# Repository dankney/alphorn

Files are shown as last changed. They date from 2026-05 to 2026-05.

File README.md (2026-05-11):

# 3D-Printable F Alphorn

A fully parametric, 3D-printable F alphorn designed for the Bambu Lab X1C with PLA wood filament. The instrument is a true F alphorn matching Jason Talbot's reference dimensions, splittable into 19 sections that all fit within a 256mm cubed build volume and join via airtight bayonet couplings.

The design is acoustically correct: the second harmonic plays at F2 (87 Hz) — the practical low note of an F alphorn — with the natural harmonic series within ±13 cents of equal temperament.

## Specifications

| | |
|---|---|
| **Pitch** | F (2nd harmonic ≈ 87 Hz) |
| **Total length** | 3880mm (388cm) |
| **Bore profile** | 14mm at mouthpiece → 92mm at bell start → 204mm at bell mouth |
| **Sections** | 19 (15 straight trunk + 3 curve + 1 bell mouth) |
| **Section length** | 204.2mm (max print height 247.7mm) |
| **Curve** | 45° upward bend (3 × 15° at the last three joints) |
| **Joint type** | Rectangular 3-lug bayonet twist-lock; sealed by friction + optional PTFE tape |
| **Wall thickness** | 9mm (trunk) → 10mm (bell), linearly interpolated |

## What's in this repository

| File | Purpose |
|---|---|
| `alphorn.scad` | Full parametric horn with assembly preview |
| `alphorn_print_layout.scad` | Self-contained file with all parts arranged flat for STL export |
| `alphorn_joint_test.scad` | Two-piece test print to validate the bayonet joint before printing all 19 sections |
| `alphorn_diagnostic.scad` | Single-section file with feature toggles for debugging mesh issues |

## Hardware required

- **Printer:** Bambu Lab X1C (or any FDM with ≥256mm build height)
- **Filament:** PLA wood (or any rigid PLA / PETG)
- **PTFE plumbers' tape** (optional, only if a joint develops a leak after assembly)
- **A mouthpiece** — not included in the print. Use either:
  - A commercial alphorn mouthpiece (Stocker, Eggerstorfer, etc.) with shank tip OD ≈ 12mm
  - The Talbot 20mm 3D-printed mouthpiece STL from [argobuilder.com](https://www.argobuilder.com/3d-printed-alphorn.html) — note: scale that STL to **10%** in the slicer

### Per-joint bolt reinforcement

The horn is too long to support itself as PLA alone — under playing-posture
loads (hands at the mouthpiece end), the first joint sees ~234,000 N·mm of
bending moment. Three M4 cap screws per joint, **oriented parallel to the
pipe axis with the threaded anchor in the female section's body wall**,
carry this load in tension alongside the bayonet lugs.

Each screw passes vertically (parallel to the pipe) from above through a
short radial tab on the upper section's body, drops through a clearance
hole in a longitudinal boss on the lower section's collar exterior, and
threads into a heat-set insert at the bottom of that boss. **Critical
geometry: 5 mm of the insert is anchored in the female section's *body*
proper (below the joint plane); only 1.4 mm sits in the collar.** This
puts the screw's lower anchor on the body side of the collar-body junction
— so even if that junction (the original failure zone) cracks, the screw
still ties the two sections together. After the +30° bayonet lock, the
three tabs land directly above the three collar bosses at 75°/195°/315°
in the lower section's frame.

Per joint:
- 3 × M4 × 30mm grade-10.9 socket-head cap screws
- 3 × M4 heat-set brass inserts (5.3 OD × 6.4 long — McMaster-Carr 92395A115 or equivalent)

Totals for the F horn (18 joints): 54 bolts, 54 inserts.
Totals for the Bb horn (13 joints): 39 bolts, 39 inserts.

Heat-press inserts into the **collar boss** pockets *before* final assembly
(soldering iron with M4 tip at ~200 °C). The 4.5 mm / 5.3 mm step in the
boss hole acts as a depth stop — the insert seats with its top at 1.4 mm
above the joint plane, leaving 18.6 mm of clearance hole above for the
screw shank. On assembly: insert the male section, twist 30° CCW to lock
the bayonet, then drive an M4 × 30 mm screw down through each tab into
the aligned insert below (~2 N·m).

## How to print

### 1. Test the joint first

Before committing to printing all 19 sections, print `alphorn_joint_test.scad` to validate the bayonet joint mechanics with your printer/filament combination. The test produces two short stubs (~50mm tall each) that share one joint at section 8/9 dimensions.

Verify after printing:

1. Lugs slide cleanly through axial slots
2. Quarter-turn locks the joint with a tactile stop
3. Joint is snug, not loose
4. Joint stays together when held vertically; halves don't pull apart under their own weight

If the lugs are too tight or too loose, adjust `BAYONET_CL` in the constants block.

### 2. Print orientation

All sections print **vertically**, small end (mouthpiece-side) **down**. This gives the cleanest bore surface, best layer adhesion along the air column, and requires no supports for sections 1-15. Sections 16-18 have an angled female face at the top — the body's flare is positioned to meet the collar's bottom rim cleanly on the low side of each tilted joint, so layer-by-layer overhangs along the body-to-collar transition stay below 25° from vertical (well within FDM bridging limits). The chamfer at the collar's open rim is the only feature on these sections that benefits from supports, and only at the rim itself; the slicer's automatic-support setting handles it.

### 3. Suggested batching plan (X1C plates)

| Plate | Contents | Approx width |
|---|---|---|
| 1 | Sections 1 + 2 | 110mm |
| 2 | Sections 3 + 4 | 120mm |
| 3 | Sections 5 + 6 | 135mm |
| 4 | Sections 7 + 8 | 155mm |
| 5 | Sections 9 + 10 | 180mm |
| 6 | Sections 11 + 12 | 205mm |
| 7 | Sections 13 + 14 | 235mm |
| 8 | Section 15 only | 134mm |
| 9 | Section 16 only | 155mm |
| 10 | Section 17 only | 175mm |
| 11 | Section 18 only | 205mm |
| 12 | Section 19 only | 227mm |

### 4. Recommended print settings

| | |
|---|---|
| Layer height | 0.2mm |
| Wall loops | 4 minimum |
| Infill (sections 1-15) | 20% |
| Infill (sections 16-19, bell) | 15% |
| Supports | None for 1-15; auto-supports at collar rim for 16-18 |
| Bed adhesion | Brim recommended for tall sections |

### 5. Workflow

1. Open `alphorn.scad` in OpenSCAD
2. Set `RENDER_SECTION = true` and `SECTION_NUMBER = N` for the section you want
3. Render with F6 (this can take a few minutes for the larger sections)
4. Export STL
5. Slice in Bambu Studio / Orca with the settings above
6. Repeat for sections 1-19

Or open `alphorn_print_layout.scad` to see all 19 sections laid out at once for visualization.

## Assembly

Each joint between adjacent sections N and N+1 works as follows:

1. **Section N+1's male end** has 3 rectangular lugs at 120° spacing protruding radially from the body wall just behind the open end
2. **Section N's female end** has a collar with three L-shaped slots cut into the inner socket — an axial entry channel and a tangential locking groove
3. **To assemble:** align the lugs on N+1 with the entry slots in N's collar, push N+1 in until the lugs bottom out, then twist about 30° to lock the lugs into the tangential lock channels. The PLA-on-PLA fit at the bayonet seals the joint by friction. If a particular joint develops a leak under playing pressure, wrap a single layer of PTFE plumbers' tape around the male shank before assembly.

Section numbers are recessed into the outer body wall at the small (male) end of each section, between the lugs — visible from outside before assembly, hidden behind the previous section's collar once joined.

For curve sections (16-18), the female collar is tilted 15° from perpendicular. The body's outer flare is shaped so the body wall reaches `collar_or` at the lowest point of the tilted joint plane (z = `len - collar_or × tan(15°)`), which makes the body's outer corner meet the collar's bottom rim within ~0.03mm on the low side of the bend. The result is a smooth body-to-collar transition all the way around the joint without an exposed ledge or unsupported overhang.

## Mouthpiece

The horn body bore at section 1's small end is 14mm ID. Standard alphorn mouthpieces have a shank tip OD of about 12mm and seat by taper friction at roughly 9mm depth into the bore. No glue, no threaded receiver — the mouthpiece simply press-fits and stays in place during play.

Sources:

- **Commercial:** Any alphorn mouthpiece (Stocker, Eggerstorfer, Tornister, etc.)
- **3D printed:** Talbot's 20mm cup mouthpiece STL on [argobuilder.com](https://www.argobuilder.com/3d-printed-alphorn.html). Important: that STL was exported at 10× scale, so import it and **scale to 10%** in your slicer. Print at 100% infill in PETG.

## Acoustic design

The bore follows a three-region profile from Talbot's reference drawings, expressed as the bore inner diameter at any axial position z:

- **Receiver (z=0 to 42mm):** linear taper from 16.7mm at the mouthpiece end down to 12.0mm at the receiver/trunk junction
- **Trunk (z=42 to 3140mm):** power law `bore_id(z) = 2 × (0.00026179 × (z − 41)^1.4849 + 5.9997)`
- **Bell (z=3140 to 3880mm):** quadratic `bore_id(z) = 0.00015273 × s² + 0.03833307 × s + 92.0` where `s = z − 3140`, C¹-continuous with the trunk slope at the junction

Each section's bore is subtracted as 8 stepped frustums following this profile, with maximum approximation error of 0.028mm. The bore is preserved at its acoustic profile right up to each joint plane — no internal flaring, no abrupt steps. The joint's mechanical clearance happens entirely above z=len in the female socket region, which is filled by the next section's male shank when assembled.

At 25°C effective playing temperature with end correction of 0.061m at the bell:

| Harmonic | Frequency | Pitch | Cents from equal temperament |
|---|---|---|---|
| 1 | 43.9 Hz | F1 (pedal) | +11 |
| **2** | **87.9 Hz** | **F2 (low note)** | **+11** |
| 3 | 131.8 Hz | C3 | +13 |
| 4 | 175.7 Hz | F3 | +11 |
| 5 | 219.7 Hz | A3 | −3 |
| 6 | 263.6 Hz | C4 | +13 |
| 8 | 351.5 Hz | F4 | +11 |

The uniform +11 cent offset reflects the assumed playing temperature; the player adjusts pitch by lipping and by Talbot's "trim to tune" technique on section 1. The 5th harmonic's natural −3 cents from equal-tempered A3 is characteristic of the harmonic series and matches the historical alphorn sound.

## Customizing the design

`alphorn.scad` is fully parametric. Key constants near the top:

| Constant | Default | Effect |
|---|---|---|
| `TOTAL_LENGTH` | 3880 | Overall horn length in mm |
| `NUM_SECTIONS` | 19 | Number of sections (don't reduce — 18 sections exceed X1C build height) |
| `CURVE_TOTAL_DEG` | 45 | Total bend angle in the bell region |
| `CURVE_JOINTS` | 3 | Number of joints sharing the bend |
| `BAYONET_CL` | 0.25 | Print clearance on lugs (increase if too tight) |
| `WALL_TRUNK` | 9.0 | Wall thickness at the mouthpiece end |
| `WALL_BELL` | 10.0 | Wall thickness at the bell mouth |

Changing these will automatically update the section profile table, batching plan, and acoustic length. Re-print the joint test if you change `BAYONET_CL`.

## Credits and references

This design is built on the work of Jason Talbot at [Argo Builder](https://www.argobuilder.com/), whose detailed measured drawings of a traditional Swiss alphorn made parametric reproduction possible:

- [Making an alphorn (wooden) — full dimensional drawings](https://www.argobuilder.com/making-an-alphorn.html)
- [3D printed alphorn — build log and STL files](https://www.argobuilder.com/3d-printed-alphorn.html)

Additional references:

- Flyby.ch [alphorn manufacture notes](http://www.flyby.ch/alphorn/herst_e.htm)

## License

Specify your preferred license here — common choices:

- **CC-BY-SA 4.0** — share-alike, requires attribution
- **MIT** — permissive, requires attribution
- **CC0** — public domain dedication

## Contributing

Pull requests welcome. If you build one of these and want to share photos or audio, please open an issue!

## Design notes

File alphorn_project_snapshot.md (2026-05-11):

# 3D Printable F Alphorn — Project Snapshot
**Date:** April 28, 2026
**Status:** OpenSCAD v7 — 19 sections, all parts fit X1C 256mm build height, print layout file complete

---

## Project Goal
Design a fully functional, playable F alphorn that can be 3D printed on a Bambu Lab X1C using PLA wood filament (via AMS), and assembled as simply as possible.

---

## Hardware & Materials
- **Printer:** Bambu Lab X1C
- **Build volume:** 256 × 256 × 256mm
- **Filament:** PLA wood filament via AMS
- **Slicer:** Bambu Studio

---

## Fundamental Geometry
The alphorn is a **single continuous hollow tapered tube** from mouthpiece to bell mouth. There is no separate bell attachment. The bell is simply where the taper flares more rapidly in the final 740mm. Each printed section is a plain hollow frustum with a rectangular bayonet joint integrated as part of the same connected mesh.

The instrument has a gentle **45° upward curve** in the bell region, distributed across the last three section joints (15°/joint × 3 joints).

---

## Files
| File | Purpose |
|---|---|
| `alphorn.scad` | Full parametric horn — 19 sections + mouthpiece + foot + assembly preview |
| `alphorn_print_layout.scad` | Self-contained file showing all parts arranged flat for printing reference |
| `alphorn_joint_test.scad` | Self-contained two-piece test print to validate the bayonet joint |

---

## Design Decisions Made
- **Tuning:** Standard F (388cm total)
- **Style:** Traditional sweeping curve (45° bend in bell region)
- **Joints:** Rectangular bayonet twist-lock with O-ring groove
- **Sections:** 19 identical-construction sections covering the full 3880mm bore
- **Bell:** NOT a separate piece — sections 17–19 are the bell region
- **Mouthpiece:** 20mm cup diameter (Talbot design), printed separately at 100% infill, shank tip seats directly in the section 1 bore by taper friction
- **Curve:** Angled female faces on sections 16, 17, 18 (15° each = 45° total)
- **Support foot:** Designed but excluded from assembly preview

---

## Section Count Rationale
The instrument was originally 18 sections × 215.6mm. Section 17 measured **258.7mm** in print orientation due to the angled female collar lifting one side ~24mm above the body — exceeding the X1C's 256mm build height. Increasing to 19 sections × 204.2mm brings worst-case section height to 247.7mm, comfortably within the build envelope while preserving the same total horn length (3880mm) and acoustic profile.

---

## Authoritative Dimension Source
Jason Talbot's alphorn drawings:
**https://www.argobuilder.com/making-an-alphorn.html**

His 3D printed alphorn build log:
**https://www.argobuilder.com/3d-printed-alphorn.html**

---

## Confirmed Dimensions

### Overall
| Parameter | Value |
|---|---|
| F horn trunk length | 314cm |
| Bell region length | 74cm |
| **Total horn length** | **388cm (3880mm)** |
| Wall thickness (trunk) | 7mm |
| Wall thickness (bell) | 8mm |

### Bore Reference Points
| Station | Inner Diameter | Outer Diameter |
|---|---|---|
| z=0mm (mouthpiece) | 14.0mm | 28.0mm |
| z=2200mm | 60.0mm | 74.0mm |
| z=3140mm (bell start) | 92.0mm | 106.0mm |
| z=3880mm (bell mouth) | 204.0mm | 220.0mm |

### Mouthpiece (Talbot 20mm)
| Parameter | Value |
|---|---|
| Total length | 105.17mm |
| Cup ID | 20.0mm |
| Cup OD | 31.84mm |
| Backbore D | 4.76mm |
| Shank length | 78.94mm |
| Shank tip OD / ID | 12.03 / 8.97mm |

The narrow shank tip inserts into the horn bore at z=0 and seats by taper friction at ~9mm depth.

---

## Bore Profile

### Trunk (z=0 to 3140mm) — Power Law
```
r(z) = 0.000250 × (z+1)^1.4849 + 6.9997
```

### Bell (z=3140 to 3880mm) — Quadratic
```
s = z - 3140
ID(s) = 0.00015474×s² + 0.036846×s + 92.0
```
C1-continuous with trunk slope at s=0. Reaches 204mm at s=740.

### Wall Thickness
Linear interpolation: 7.0mm at z=0 → 8.0mm at z=3880.

### Bore Subtraction
8-step subdivided frustum subtraction follows the curved profile. Max error 0.028mm. Bore is uninterrupted from z=0 to z=len within each section — **no internal flare** at joints. The bore preserves its acoustic profile right up to each joint plane. For curve sections (16–18), an additional bore extension above z=len prevents any solid-material plug from the angled-cut overhang.

### Full Section Profile Table (19 sections × 204.2mm)
| n | z_start | z_end | ID_start | ID_end | OD_start | OD_end | Curve? | Print Height |
|---|---|---|---|---|---|---|---|---|
| 1 | 0.0 | 204.2 | 14.00 | 15.39 | 28.00 | 29.54 | | 224.2mm |
| 2 | 204.2 | 408.4 | 15.39 | 17.86 | 29.54 | 32.13 | | 224.2mm |
| 3 | 408.4 | 612.6 | 17.86 | 21.04 | 32.13 | 35.45 | | 224.2mm |
| 4 | 612.6 | 816.8 | 21.04 | 24.79 | 35.45 | 39.36 | | 224.2mm |
| 5 | 816.8 | 1021.1 | 24.79 | 29.04 | 39.36 | 43.78 | | 224.2mm |
| 6 | 1021.1 | 1225.3 | 29.04 | 33.71 | 43.78 | 48.62 | | 224.2mm |
| 7 | 1225.3 | 1429.5 | 33.71 | 38.78 | 48.62 | 53.85 | | 224.2mm |
| 8 | 1429.5 | 1633.7 | 38.78 | 44.20 | 53.85 | 59.43 | | 224.2mm |
| 9 | 1633.7 | 1837.9 | 44.20 | 49.95 | 59.43 | 65.34 | | 224.2mm |
| 10 | 1837.9 | 2042.1 | 49.95 | 56.01 | 65.34 | 71.55 | | 224.2mm |
| 11 | 2042.1 | 2246.3 | 56.01 | 62.36 | 71.55 | 78.06 | | 224.2mm |
| 12 | 2246.3 | 2450.5 | 62.36 | 69.00 | 78.06 | 84.86 | | 224.2mm |
| 13 | 2450.5 | 2654.7 | 69.00 | 75.91 | 84.86 | 91.93 | | 224.2mm |
| 14 | 2654.7 | 2858.9 | 75.91 | 83.10 | 91.93 | 99.27 | | 224.2mm |
| 15 | 2858.9 | 3063.2 | 83.10 | 90.55 | 99.27 | 106.87 | | 224.2mm |
| 16 | 3063.2 | 3267.4 | 90.55 | 105.51 | 106.87 | 121.91 | **female 15°** ← bell | 240.3mm |
| 17 | 3267.4 | 3471.6 | 105.51 | 127.87 | 121.91 | 144.34 | **female 15°** | 243.1mm |
| 18 | 3471.6 | 3675.8 | 127.87 | 160.17 | 144.34 | 176.71 | **female 15°** | 247.7mm |
| 19 | 3675.8 | 3880.0 | 160.17 | 204.00 | 176.71 | 220.00 | (open mouth) | 204.2mm |

All sections fit within X1C 256 × 256 × 256mm build volume.

---

## Bayonet Joint Specification

Rectangular lugs and L-shaped slots in the female collar:

| Parameter | Value | Purpose |
|---|---|---|
| Lug count | 3 (at 120°) | Symmetric lock |
| Engagement depth | 15mm | Travel from open face to lock |
| Lug — radial (BAYONET_LUG_H) | 3.5mm | Protrusion outward |
| Lug — tangential (BAYONET_LUG_W) | 8mm | Width along circumference |
| Lug — axial (BAYONET_LUG_T) | 5mm | Thickness in slide direction |
| Lug embed (LUG_EMBED) | 1.0mm | Cube extends inward into body wall |
| Collar length | 20mm | At each end |
| Print clearance | 0.25mm | On lugs |
| O-ring groove | 2.5mm × 2.2mm | Fits 2mm cross-section O-ring |
| O-ring Z position (ORING_Z) | 10mm | Body-local z, just above lugs |
| Lock rotation | ~30° | Quarter-twist sweep |

---

## Unified Joint Methodology

**Every section uses one `difference()` block:**

**Outer hull (union):**
1. Body frustum (`od0` → `od_at_flare`)
2. External flare to collar OD (only if female end exists)
3. Female collar block on appropriate plane (only if female end exists)
4. Male lugs embedded 1mm into body wall (only if n > 1)

For curve sections, the body+flare are intersected with a tilted half-space below the collar plane.

**Subtractions:**
1. Bore profile (8-step curved frustum, z=0 to z=len)
2. Bore extension above z=len (curve sections only)
3. Inner socket (collar region, on tilted plane for curve sections)
4. L-channels (lug paths)
5. O-ring groove (cuts circumferential channel into outer body wall at ORING_Z=10)

### Per-Section Pieces
| Section | Female end | Male end | Notes |
|---|---|---|---|
| 1 | ✓ collar | — | Mouthpiece end (no male side) |
| 2–15 | ✓ collar | ✓ lugs + O-ring | Standard sections |
| **16** | ✓ collar (**15° angled**) | ✓ lugs + O-ring | First curve joint (bell start) |
| **17** | ✓ collar (**15° angled**) | ✓ lugs + O-ring | Curve joint |
| **18** | ✓ collar (**15° angled**) | ✓ lugs + O-ring | Curve joint |
| 19 | — (open bell mouth) | ✓ lugs + O-ring | Bell mouth section |

The test file (`alphorn_joint_test.scad`) uses identical joint methodology to a generic interior section.

---

## Curve Implementation
Sections 16, 17, 18 have their female end face cut at 15° instead of perpendicular. The female collar sits on the tilted face plane. Mating section's perpendicular male collar rotates that section's body axis by 15°.

- 45° total bend in bell region
- No length added — curves at existing joints
- OD unchanged at faces; wall thickness preserved
- Bore stays open with 15° kink at each joint (acoustically negligible at wide bell end)

Assembly preview uses recursive forward kinematics (`place_section_chain`) — walks up the horn, applying 15° rotation at each curve joint.

---

## OpenSCAD Module Inventory (`alphorn.scad`)
| Module / Function | Purpose |
|---|---|
| `bore_id(z)` | Inner diameter at any z (power law trunk + quadratic bell) |
| `wall_at(z)` | Wall thickness, linear 7→8mm |
| `bore_od(z)` | Outer diameter at z |
| `is_curve_section(n)` | True for sections 16, 17, 18 |
| `cumulative_curve(n)` | Total bend angle accumulated through section n |
| `taper_tube()` | Standalone hollow frustum |
| `horn_section(n)` | Single difference() that produces a complete connected section |
| `l_channels_only(od)` | L-shaped lug paths |
| `male_lugs(od)` | Three rectangular lugs embedded 1mm into body wall |
| `oring_groove(od, id)` | Circumferential channel cut into outer wall at ORING_Z=10 |
| `mouthpiece()` | 20mm cup mouthpiece, shank tip at z=0 |
| `support_foot()` | Ground peg with saddle clamp |
| `place_section_chain(n)` | Recursive forward kinematics for assembly preview |
| `full_assembly()` | Complete preview render |

### Render Control
```openscad
RENDER_ASSEMBLY   = true;   // full preview
RENDER_MOUTHPIECE = false;
RENDER_SECTION    = false;  // set SECTION_NUMBER = 1–19
RENDER_FOOT       = false;
```

---

## Print Layout File (`alphorn_print_layout.scad`)
Self-contained, no external dependencies. Renders all 19 sections + mouthpiece + foot arranged flat on the XY plane in optimal print orientation. Useful for visualizing the parts list.

### Batching Plan (X1C plates)
| Plate | Contents | Width |
|---|---|---|
| 1 | Sections 1 + 2 | ~110mm |
| 2 | Sections 3 + 4 | ~120mm |
| 3 | Sections 5 + 6 | ~135mm |
| 4 | Sections 7 + 8 | ~155mm |
| 5 | Sections 9 + 10 | ~180mm |
| 6 | Sections 11 + 12 | ~205mm |
| 7 | Sections 13 + 14 | ~235mm |
| 8 | Section 15 only | |
| 9 | Section 16 only | |
| 10 | Section 17 only | |
| 11 | Section 18 only | |
| 12 | Section 19 only | |
| 13 | Mouthpiece + foot | |

---

## Parts List
| Part | Qty | Notes |
|---|---|---|
| Horn sections 1–15 | 15 | Standard sections, perpendicular female face |
| Horn sections 16–18 | 3 | Angled (15°) female face for curve |
| Horn section 19 | 1 | Bell mouth, no female collar |
| Mouthpiece (20mm) | 1 | 100% infill |
| Support foot | 1 | Optional |
| O-rings (2mm cross-section) | 18 | One per joint |

---

## Open Issues / Next Steps

### Priority — next to do:
1. **Print the test file** (`alphorn_joint_test.scad`) — validate joint mechanics with PLA wood on X1C.
2. **Tune clearance if needed** — adjust `BAYONET_CL` based on test print fit.
3. **Visual verification of curve** — render the assembly preview and confirm the curve matches the photos.
4. **Bell mouth ring** — decorative/structural ring at section 19 exit.
5. **Tuning allowance** — Section 1 could be printed +160mm oversize for trim-to-tune.

### Nice-to-haves:
- AMS color accent rings at bayonet collars
- Edelweiss / Swiss cross relief on bell exterior
- Assembly jig for angled curve joints

---

## Print Settings (recommended)
| Setting | Value |
|---|---|
| Layer height | 0.2mm |
| Wall loops | 4 minimum |
| Infill — sections 1–15 | 20% |
| Infill — sections 16–19 (bell) | 15% |
| Infill — mouthpiece | 100% |
| Supports | None for sections 1–15, possibly partial for 16–18 angled overhang |
| Print orientation | Vertical, small end up |

---

## Known Issues Resolved
| Issue | Resolution |
|---|---|
| Wrong bore dimensions (11mm mouthpiece end) | Corrected to 14mm |
| Piecewise linear bore kink at 220cm | Smooth power law + quadratic |
| Bell modelled as separate piece | Removed — bell is sections 17–19 of same continuous tube |
| Internal geometry inside tube | Removed — sections are plain hollow frustums |
| Linear bore subtraction left 1.8mm ring inside bell | Fixed with 8-step subdivided bore subtraction |
| Support foot appearing inside bell in assembly | Removed from assembly preview |
| Mouthpiece receiver (wider pipe at mouthpiece end) | Removed — shank seats directly in bore |
| Stale no-op difference block in section 1 | Removed |
| Straight stick instead of curved alphorn | Added 45° bell curve via angled female faces on curve sections |
| Round slots / round lugs (geometry mismatch) | Rectangular lugs + L-shaped (rotate_extrude) slots |
| Cartesian cube slots left 0.293mm material slivers at edges | Slots and lock channels use rotate_extrude |
| Female collar floating disconnected from body | Body and collar unioned into single outer hull |
| Internal flare changed bore acoustics | External flare only — bore stays on profile to joint plane |
| Lugs only tangent-line-attached to curved body wall | Lugs embedded 1mm radially into body wall, unioned into outer hull |
| Curve sections had bore plug from angled-cut overhang | Bore extension cylinder added above z=len for curve sections |
| Lugs and O-ring groove placed below z=0 (outside body) | Removed bogus translate; ORING_Z=10 placed inside body |
| Curve section body construction inconsistent with straight | Unified outer hull construction; tilted half-space intersection only |
| **Section 17 was 258.7mm tall — exceeded 256mm build height** | **Increased section count from 18 to 19; max height now 247.7mm** |

---

## Reference Links
- Talbot wooden alphorn drawings: https://www.argobuilder.com/making-an-alphorn.html
- Talbot 3D printed alphorn + Fusion 360 files: https://www.argobuilder.com/3d-printed-alphorn.html
- Flyby.ch manufacture notes: http://www.flyby.ch/alphorn/herst_e.htm

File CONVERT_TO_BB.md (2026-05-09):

# Converting the F Alphorn to Bb

This document describes the parameter changes needed to generate a Bb alphorn from this design, keeping the leadpipe and mouthpiece receiver unchanged so the same mouthpiece works on either instrument.

> **If you just want to print the Bb horn**, use the pre-built `Bb_alphorn.scad` and `Bb_alphorn_print_layout.scad` files in this repository — the parameter changes below have already been applied. The rest of this document explains *why* those files have the values they do, and how to convert to other pitches.

## Overview

The Bb alphorn is approximately 25% shorter than the F alphorn because Bb2 (116.54 Hz) is a perfect fourth above F2 (87.31 Hz). For an open conical/expanding pipe, the playing pitch is inversely proportional to the acoustic length, so a higher pitch requires a shorter horn.

The leadpipe and mouthpiece receiver (z=0 to z=42mm, bore narrows from 16.7mm to 12mm) stay identical. Only the trunk and bell are rescaled.

## Length scaling

| | F horn | Bb horn |
|---|---|---|
| Target 2nd harmonic | F2 = 87.31 Hz | Bb2 = 116.54 Hz |
| Length ratio (Bb/F) | — | 0.754 |
| Total physical length | 3880mm (388cm) | 2935mm (294cm) |
| Receiver (unchanged) | 0-42mm, 16.7→12 | 0-42mm, 16.7→12 |
| Trunk | 42-3140mm, 12→92 | 42-2378mm, 12→69.4 |
| Bell | 3140-3880mm, 92→204 | 2378-2935mm, 69.4→154 |

The acoustic length ratio scales the trunk and bell uniformly. The receiver doesn't scale because its purpose is mouthpiece fitment, not pitch — its acoustic contribution is small relative to the trunk.

## Parameter changes in `alphorn.scad`

Replace the existing constants with these values:

```scad
TOTAL_LENGTH      = 2935;       // mm (was 3880)
TRUNK_LENGTH      = 2378;       // mm (was 3140) — where bell starts
NUM_SECTIONS      = 14;         // (was 19) — fewer sections needed,
                                //   chosen so the worst curve section
                                //   stays inside the X1C 256mm build
                                //   height (NUM_SECTIONS=13 would put
                                //   sections 10-12 above 256mm)

// Receiver — UNCHANGED
RECEIVER_LEN      = 42;         // mm
RECEIVER_TIP_ID   = 16.7;       // mm
RECEIVER_END_ID   = 12.0;       // mm

// Trunk power-law constants — refit so bore=12mm at z=42 and 69.36mm at z=2378
BORE_A            = 0.00028540; // (was 0.00026179)
BORE_N            = 1.4849;     // (unchanged)
BORE_C            = 5.9997;     // (unchanged — equals 6 by construction)

// Bell quadratic constants — refit, C¹-continuous with new trunk slope at z=2378
BELL_A            = 0.00020673; // (was 0.00015273)
BELL_B            = 0.03644530; // (was 0.03833307)
BELL_C            = 69.3586;    // (was 92.0) — bore at start of bell
```

Other constants (wall thickness, bayonet dimensions, clearances) stay the same. The wall thickness function `wall_at(z) = WALL_TRUNK + (WALL_BELL - WALL_TRUNK) * (z / TOTAL_LENGTH)` interpolates by fraction of total length, so it automatically adjusts for the shorter horn.

## Sections

The Bb horn uses 14 sections of 209.6mm each. The print height of the worst-case section (section 13, the last curve section) reaches 246.7mm — comfortably inside the X1C's 256mm build envelope and roughly the same margin as the F horn's worst case (247.7mm).

A naive `2935 / 13 ≈ 226mm` per-section calculation would seem to fit the X1C too, but it actually doesn't: the curve sections (with their tilted collars) gain `collar_or × sin(15°) + collar_h × cos(15°)` ≈ 37mm of extra height on top of the section length, and at 13 sections, sections 10-12 land between 257 and 262mm. NUM_SECTIONS = 14 is the smallest count that fits all curve sections under 256mm.

| | F horn | Bb horn |
|---|---|---|
| Sections | 19 | 14 |
| Section length | 204.2mm | 209.6mm |
| Worst-case section height | 247.7mm | 246.7mm |
| Curve placement | Last 3 joints (15° each) | Last 3 joints (15° each) |
| Total bend | 45° | 45° |

The curve position (last 3 joints) and per-joint angle (15°) stay the same since these define the visual character of the alphorn rather than the pitch.

## Acoustic verification

| | F horn | Bb horn |
|---|---|---|
| Acoustic length (with bell end correction) | 3941mm | 2982mm |
| Predicted 2nd harmonic (at 25°C) | 87.87 Hz | 116.15 Hz |
| Target | F2 = 87.31 Hz | Bb2 = 116.54 Hz |
| Cents from equal-tempered | +11 | −6 |

Both horns are within typical "lip into tune" range for a brass instrument. The player adjusts pitch by lipping and by Talbot's "trim to tune" technique on the mouthpiece end of section 1.

## Mouthpiece compatibility

Because the receiver geometry is unchanged, **the same mouthpiece works on both horns**. A standard alphorn mouthpiece with a 12mm-OD shank tip seats by taper friction at ~14mm depth into the receiver, regardless of which horn it's on. The Talbot 20mm 3D-printed mouthpiece STL (scaled to 10% in the slicer) works on both.

## Joint hardware

Bayonet dimensions (`BAYONET_LUG_H`, `BAYONET_LUG_W`, `BAYONET_LUG_T`, `BAYONET_COLLAR`, `BAYONET_CL`) stay the same. The joint is sized for mechanical strength and printability, not pitch. PTFE plumbers' tape (if needed at all) works the same way on either horn.

The curve sections' body-to-collar flare geometry — where the body's outer flare reaches `collar_or` at z = `len − collar_or × tan(angle)` so the body's outer corner coincides with the collar's bottom rim on the low side of each tilted joint — is computed per-section from `collar_or` (which depends on the section's own bore) and `angle` (which is the per-joint curve angle, unchanged at 15°). It auto-adjusts for the smaller `collar_or` values of the Bb horn's curve sections without any code changes. Spot-check after conversion that `body_h_c = flare_top_z_c − flare_h` remains positive for the curve sections; for typical alphorn proportions across pitches from C through Eb, this is comfortably the case.

## Implementation steps

1. Edit `alphorn.scad` with the parameter changes above (or start from the prebuilt `Bb_alphorn.scad` if you have it)
2. Re-render the assembly preview to verify the curve and overall proportions look right
3. Run the acoustic verification (Phase 9 prompt 23 in `RECREATE_WITH_CLAUDE.md`) — predicted 2nd harmonic should be ~116 Hz
4. Regenerate `alphorn_print_layout.scad` from scratch — the layout was generated for 19 sections and the section count, length, and OD profile all change for Bb
5. Print a fresh joint test piece. The joint geometry is unchanged so the existing F-horn test print still validates the fit; the dimensions sample at mid-section (around the section 7/8 boundary in the 14-section design)
6. Print all 14 sections per the new batching plan

## Bore profile reference points (Bb horn)

For verification or comparison:

| z (mm) | Region | Bore ID (mm) |
|---|---|---|
| 0 | Receiver tip | 16.70 |
| 42 | Receiver / trunk junction | 12.00 |
| 500 | Trunk | 17.12 |
| 1000 | Trunk | 27.28 |
| 1500 | Trunk | 40.50 |
| 2000 | Trunk | 56.14 |
| 2378 | Trunk / bell junction | 69.36 |
| 2700 | Bell | 102.53 |
| 2935 | Bell mouth | 153.80 |

## Other pitches

The same approach works for any alphorn pitch. The length scaling factor is `f_F / f_target`, where `f_target` is the desired 2nd harmonic. Common alphorn pitches:

| Pitch | 2nd harmonic | Scale factor (vs F) | Approx. total length |
|---|---|---|---|
| Eb (concert pitch) | 77.78 Hz | 1.123 | 4357mm |
| E | 82.41 Hz | 1.060 | 4112mm |
| F | 87.31 Hz | 1.000 | 3880mm |
| F# | 92.50 Hz | 0.944 | 3661mm |
| G | 98.00 Hz | 0.891 | 3457mm |
| Ab | 103.83 Hz | 0.841 | 3262mm |
| A | 110.00 Hz | 0.794 | 3079mm |
| Bb | 116.54 Hz | 0.749 | 2935mm |
| B | 123.47 Hz | 0.707 | 2742mm |
| C | 130.81 Hz | 0.667 | 2589mm |

For each pitch, recompute `BORE_A`, `BORE_C`, `BELL_A`, and `BELL_B` to fit:
- Trunk: 12mm at z=42, scaled-92 at the new TRUNK_LENGTH
- Bell: scaled-92 at TRUNK_LENGTH, scaled-204 at TOTAL_LENGTH
- Bell slope at TRUNK_LENGTH must match the trunk slope (C¹ continuity)

The receiver and joint dimensions stay constant across all pitches — only TOTAL_LENGTH, TRUNK_LENGTH, NUM_SECTIONS, and the four bore/bell constants change.

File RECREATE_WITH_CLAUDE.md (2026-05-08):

# Recreating the F Alphorn Design with Claude Opus 4.7

This document captures the sequence of prompts that produced the parametric F alphorn OpenSCAD model in this repository. Each prompt is written as a standalone instruction Claude can act on; the sequence reflects the iterative discovery process that uncovered constraints and bugs along the way.

The original session took many hours and went through several major redesigns as constraints surfaced — bore profile, joint mechanics, mesh integrity, FDM printability, label visibility, and acoustic continuity all interacted in ways that weren't obvious up front. This guide bakes those lessons in so a recreation can be more efficient.

## How to use this document

Open a Claude conversation with **Opus 4.7** (the model needs strong spatial reasoning and patience for long iterative debugging). Feed the prompts in order, one at a time, waiting for Claude to produce code and confirm before proceeding. After major milestones, ask Claude to "take a snapshot" so you have rollback points if a later change breaks something.

You will need to provide Claude with reference material at the appropriate steps — primarily Jason Talbot's dimensional drawings from [argobuilder.com](https://www.argobuilder.com/making-an-alphorn.html). Download those drawings as images (sheets 1-8) and upload them when prompted.

If a step doesn't produce the expected result, don't push forward — debug in place. The single biggest lesson from the original session was that downstream geometry depends critically on the soundness of upstream geometry, and shortcuts compound. The second biggest lesson was that geometry that looks right in the OpenSCAD preview can still be broken in the STL export — always verify in the slicer.

## Prerequisites

Make sure these are mentioned to Claude up front (or set as part of an early prompt):

- Target printer: Bambu Lab X1C, 256mm cubed build volume
- Target filament: PLA wood (via AMS)
- Target slicer: Bambu Studio / Orca Slicer
- Output format: OpenSCAD `.scad` files
- The horn must be airtight, acoustically correct, splittable into print-bed-sized sections, and reassemblable without tools

## Phase 1: Establish the basic instrument

### Prompt 1 — Initial design brief

> I want to design a 3D-printable F alphorn for my Bambu Lab X1C printer using PLA wood filament. The instrument should be acoustically correct and playable. Please use Jason Talbot's dimensional drawings from argobuilder.com as the authoritative source. Plan an initial parametric OpenSCAD design that splits the horn into sections small enough to fit on the X1C bed (256mm cubed). Each section should have an integrated joint mechanism so the horn can be assembled and disassembled. The horn should be a single continuous tapered tube — the bell is just the final sections of the same bore where it flares more rapidly, not a separate piece.

### Prompt 2 — Provide reference dimensions

> I'm uploading the eight Talbot dimensional drawing sheets (IMG_5096-5104). Please extract the bore profile dimensions, wall thicknesses, and total length from these drawings and use them as the authoritative source for the model. The horn should be 388cm total (Talbot's F# spec of 373cm + 16cm tuning extension to make F).

(Upload the Talbot drawing scans here.)

### Prompt 3 — Bore profile with mouthpiece receiver

> The bore profile has three regions:
>
> 1. **Mouthpiece receiver (leadpipe tip)**, z=0 to z=42mm: linear taper NARROWING from 16.7mm at the very tip to 12.0mm at z=42. This is the only region where the bore narrows — it provides the cup-like constriction needed for a mouthpiece to seat by taper friction.
> 2. **Trunk**, z=42 to z=3140mm: power-law expansion from 12mm at z=42 to 92mm at z=3140. Use form `bore_id(z) = 2*(A*(z-42+1)^N + C)` with N≈1.4849 and fit A and C to those endpoints.
> 3. **Bell**, z=3140 to z=3880mm: quadratic, C¹-continuous with the trunk slope at z=3140, reaching 204mm at z=3880.
>
> Wall thickness should linearly interpolate from 7mm at z=0 to 8mm at z=3880.

### Prompt 4 — Snapshot

> Take a snapshot. Save the current files as a timestamped zip so we can roll back if needed.

## Phase 2: Add the curve

### Prompt 5 — Distributed curve

> The horn should have a 45° upward bend in the bell region, distributed across the last three section joints (15° per joint). Implement this by angling the female mating face of the affected sections at 15° instead of perpendicular. The mating section attaches perpendicular to that tilted face, so its body axis ends up rotated 15° relative to the previous section. Each individual printed section remains a straight piece — the curve emerges from how they connect. Add an assembly preview that uses recursive forward kinematics to walk up the horn applying the rotation at each curve joint.

## Phase 3: Bayonet joint design

### Prompt 6 — Initial joint geometry

> Design a bayonet twist-lock joint between sections. **Do NOT include an O-ring groove** — relying on O-rings means sourcing 18 different stretch sizes, and PLA-on-PLA friction at the bayonet is sufficient. PTFE plumbers' tape can be added at assembly if a leak appears. Each joint should have:
>
> - A male collar at the small end of each section (sections 2-19) with 3 rectangular lugs at 120° spacing, each 8mm tangentially × 5mm axially × 3.5mm radially
> - A female collar at the large end of each section (sections 1-18) with three L-shaped slots cut into the inner socket — an axial entry channel for the lug to insert, plus a tangential lock channel that engages when the male is rotated ~30°
> - Lugs embedded 1mm into the body wall (cube inner face goes from `od/2 - 1` to `od/2 + 3.5` so the lug overlaps the body's curved surface in 3D, not just on a tangent line)
> - Slots and lock channels swept using `rotate_extrude` of a square profile so all edges follow the cylinder's curvature

### Prompt 7 — Iterative joint debugging

These prompts may be needed depending on what surfaces. Apply only as relevant:

> The female collar is rendering as a separate piece adjacent to the body rather than being part of the same mesh. Restructure `horn_section` so the body, flare, and collar are all unioned into a single outer hull, then all subtractions (bore, inner socket, L-channels) happen in one `difference()`. This guarantees a single connected mesh.

> There is a visible air gap between the female collar and the segment body where the radii change. Add a 0.5mm overlap so the collar extends slightly into the body region (3D volume overlap, not just a 2D shared face).

> The whole horn should have an unobstructed air path from mouthpiece to bell. There are obstructions on curve sections — the angled female face cuts the body at 15°, leaving body material above z=len that the bore subtraction doesn't reach. Add a constant-radius bore extension above z=len for curve sections to prevent any solid-material plug.

### Prompt 8 — Snapshot

> Take a snapshot.

## Phase 4: Print layout and printability

### Prompt 9 — Self-contained print layout

> Without modifying the main model, create a separate self-contained OpenSCAD file that arranges all parts on the XY plane in optimal print orientation (small end down for sections). Don't reference the main model with `use` or `include` — copy all needed constants and modules so the file works on its own. Include a batching plan in the comments showing which sections fit together on a single 256mm bed plate.

### Prompt 10 — Build height check

> The largest sections might exceed the X1C's 256mm build height when printed vertically. Calculate the precise print height for each section, accounting for the angled collar lift on curve sections (where one side of the tilted collar rises by `collar_or × sin(15°)`). If any section exceeds 256mm, increase the section count and reduce per-section length until all fit, while keeping total horn length and the curve placement unchanged.

### Prompt 11 — FDM printability of angled rim

> The angled female face on curve sections has overhangs flatter than 45° from horizontal at the rim — too flat for FDM without supports. Add a 45° chamfer (5mm × 5mm) at the outer rim of every female collar that bevels the open face. Apply to all sections so straight sections also get a clean rim, but it's especially critical for the curve sections where the face is tilted.

### Prompt 12 — Smooth body-to-collar transition

> Add a gentle slope at the body-to-collar transition. The flare zone where the body OD widens up to the collar OD should be 25mm long, giving roughly a 17° slope from vertical — very gentle and visually seamless with no abrupt edge.

### Prompt 13 — Printable lug bottoms

> The bottom face of each male lug at z=2.5 has a 3.5mm radial overhang past the body wall — too wide for FDM bridging. Rebuild each lug as a `hull()` of two pieces: a top cube with the original full radial extent (engages with the lock channel), and a thin bottom slab that protrudes only 1mm past the body wall. The hull creates a 45° printable ramp on the outer-bottom corner of each lug. The top portion still has full extent so it engages firmly with the female lock channel — the chamfered bottom region just doesn't engage with the channel walls (which is fine, since locking happens at the lug's top face).

### Prompt 13b — Curve-section body-to-collar overhang (the "low side ledge")

> On curve sections (16-18), the standard body polygon flares from `od_at_flare/2` at z=`body_h` up to `collar_or` at z=`len`, then continues at constant `collar_or` to z=`len + max_overhang`. The whole polygon is then clipped at the tilted joint plane (`z = len + y·tan(angle)`). On the LOW side of the tilted plane, this clip cuts the body well before the flare reaches `collar_or`, leaving the body wall ending at a smaller radius than the collar's bottom rim — which sits 2-6mm outboard. The visible result is a sharp 85°+ overhang where the slicer has to bridge from body wall outline to collar wall outline within a single layer. Slicer's overhang detector flags it as severe, and the rim arches print with stringy/sagging layers.
>
> The fix is geometric, not additive: move the flare's top vertex from `(collar_or, len)` to `(collar_or, len - collar_or × tan(angle))`. That z is the exact height where the tilted clip plane on the low side would intersect the body cylinder at radius `collar_or`. With the new vertex, the body's outer corner on the low side coincides (within ~0.03mm) with the collar's bottom rim. Above that vertex, the polygon stays at constant `collar_or` up to `len + max_overhang`, so the tilted clip carves a clean joint plane that runs straight into the collar at every angle around the section.
>
> Compute the new flare bottom vertex consistently:
> ```scad
> flare_top_z_c = len - collar_or * tan(angle);
> body_h_c     = flare_top_z_c - flare_h;
> od_at_flare_c = od0 + (od1 - od0) * (body_h_c / len);
> ```
> Use these in the polygon for curve sections only — straight sections (`angle == 0`) are unchanged because `tan(0) = 0`, which collapses `flare_top_z_c` back to `len`. Worst-case layer-by-layer overhangs along the body-to-collar transition drop from 85°+ to under 25° from vertical, which is well within FDM bridging limits and stops the slicer from flagging the joint.
>
> Important things NOT to do, even though they look reasonable in isolation: do **not** add a tilted "flange" or downward extension of the collar to fill the ledge. A tilted addition has its bottom edge at a different world z at every angle, so the bottom edge dips low on the LOW side where the body is narrow — the flange's bottom edge then sticks 2-6mm outboard of the body wall there, recreating the same severe overhang one layer below where it started. Any solution that tries to bridge the ledge with material added OUTSIDE the body's existing rotate-extruded polygon will hit this trap. The fix has to be in the polygon itself.

## Phase 5: Mesh integrity (critical iteration)

The original session encountered persistent disconnected-mesh problems that took many iterations to fully resolve. The OpenSCAD preview will show one piece, but the STL export can have disconnected shells. **Always slice the STL in Orca and check** — don't trust the preview.

### Prompt 14 — Detect disconnected shells

> When I split this design into print objects in Orca Slicer, I see N thin rings appearing as separate objects. The geometry is supposed to be a single connected mesh per section. Audit the model for adjacent solids that share only a 2D face (or near-degenerate boundaries from nested boolean operations) — those produce separate mesh shells in STL export even though OpenSCAD's CSG considers them unioned.

### Prompt 15 — Restructure as single rotate_extrude

> Replace the stacked-cylinder construction (body + flare + collar as separate cylinders unioned together) with a single `rotate_extrude` of a closed 2D polygon that traces the entire outer profile from base through the flare and collar in one continuous path. This guarantees one solid with no internal shared faces. For curve sections that need a tilted collar, keep the rotate_extrude for the body+flare and add the tilted collar as a separate solid with a small overlap.

### Prompt 16 — Diagnostic file for ring isolation

> If rings are still appearing, create a diagnostic OpenSCAD file with a single section and feature toggle flags at the top (`FEATURE_FLARE`, `FEATURE_FEMALE_COLLAR`, `FEATURE_INNER_SOCKET`, `FEATURE_L_CHANNELS`, `FEATURE_SECTION_LABEL`, `FEATURE_COLLAR_CHAMFER`, `FEATURE_MALE_LUGS`, `FEATURE_BORE`). I'll toggle features on one at a time, export STL, and check Orca to identify which feature introduces the disconnect. Don't guess at the cause — the bisection takes 5-10 minutes and gives a definitive answer.

### Prompt 17 — Eliminate degenerate boundaries

> If a feature is identified as the disconnect source, look for nested `difference()` operations or subtraction shapes whose outer boundary lies essentially on the body's outer surface (within 0.1mm). These produce near-degenerate boundaries in CGAL that become disconnected shells. Rewrite any such shape using a single `rotate_extrude` of a polygon profile, and extend any subtraction shapes well beyond the body OD (5mm past) so there's no marginal overlap with the body's outer surface.

## Phase 6: Section labels — get this right the first time

The original session went through **four different label placement attempts** before settling on the working one. Skip the failures by going straight to the right answer.

### Prompt 18 — Section labels on body wall between lugs

> Each section should have its number recessed into the OUTER body wall at the small (male) end of each section, in the clear space between the lugs (lugs at 0°, 120°, 240°; place label at 60°). Position parameters:
>
> - z = 18mm above the section's bottom face (well above lug top at z=7.5)
> - Angular position: 60° (between two adjacent lugs)
> - TEXT_SIZE = 16mm character height
> - TEXT_DEPTH = 1.2mm recess depth
> - Bold sans-serif font (Liberation Sans:style=Bold)
>
> Implementation gotchas:
>
> 1. The text shape must extrude RADIALLY INWARD into the wall, not outward into empty space. Position the text origin at `r = od0/2 + TEXT_DEPTH` and use `rotate([0, -90, 0]) rotate([0, 0, -90])` so the local +Z extrusion direction points inward toward the body axis.
> 2. Add `mirror([1, 0, 0])` before the linear_extrude — without it, when viewed from outside the body, the digits read mirrored (e.g., "10" appears as "01").
> 3. Make the extrude height slightly more than TEXT_DEPTH (TEXT_DEPTH + 0.2) to ensure full cut-through.
>
> The label is recessed into the body wall just above the lug zone, always visible from outside before assembly, hidden inside the previous section's collar after assembly. This is on a simple cylindrical surface that's identical for every section regardless of curve angle, so it works uniformly across all sections.

**Anti-patterns to avoid** — these were tried and failed:

- Recessed text on the inner socket wall (not visible looking down into a 20mm-deep socket)
- Embossed text on the flat top face of the collar (would create a 0.8mm gap at every joint when assembled, blocking the seal)
- Recessed text on the collar's outer cylindrical surface (works for straight sections but the angled rim of curve sections cuts through it unpredictably)

The body wall between lugs is the only location that works for all sections.

## Phase 7: Bore continuity at joints

### Prompt 19 — No "print ramp" inside the body

> Do NOT add an internal ramp or chamfer that widens the bore at the top of each body section, even if it would help printability when printing collar-down. Such a ramp creates a 6-7mm thick annular pocket of dead air at every joint when assembled — section N's widened bore opens into the smaller-bore start of section N+1, leaving an empty annular cavity around the bore. This is acoustically destructive (18 such pockets in series).
>
> The bore at every joint must be continuous: section N's bore at z=len equals section N+1's bore at z=0 because both evaluate `bore_id` at the same absolute z. If printing collar-down has overhang issues, the fix is to print small-end-down instead (the original orientation), or use slicer-generated supports. Don't compromise the bore.

### Prompt 20 — Handle the receiver kink in bore subtraction

> Section 1's bore profile has a kink at z=42mm where the receiver taper (narrowing) meets the trunk expansion. The default 8-step frustum approximation linearly interpolates across this kink and will be off by ~0.7mm at z=42. Fix this for section 1 specifically: use a single cone subtraction for the receiver (z=0 to z=42), then start the standard 8-frustum subdivision at z=42 for the trunk portion. This places the kink exactly on a frustum boundary so it's rendered without approximation error.

### Prompt 21 — Snapshot

> Take a snapshot.

## Phase 8: Joint test print

### Prompt 22 — Bayonet joint test print

> Before committing to printing all 19 sections, create a self-contained two-piece test print file that validates the bayonet joint mechanics. Use the dimensions from the section 8/9 boundary (mid-trunk size — representative without being huge). Each test piece should be a short body stub (~50mm tall) with one half of the joint attached. Include verification steps in the file's header comments: lugs slide cleanly through slots, quarter-turn locks the joint, joint is snug but not too tight, joint stays together when held vertically. If the lugs are too tight or too loose, adjust `BAYONET_CL` (default 0.25mm).

## Phase 9: Verification

### Prompt 23 — Acoustic verification

> Verify acoustically that the design is correctly pitched in F. Check the harmonic series at typical playing temperature (warm humid breath inside the horn ≈ 25°C). The 2nd harmonic (the practical low note of an F alphorn) should be approximately F2 (87.31 Hz). Calculate the fundamental and at least the first 8 harmonics, comparing each to its equal-tempered target in cents. Account for end correction at the bell mouth (≈0.6 × bell_radius). Also verify the bore matches Talbot's reference points: 14mm at z=0 (was — now 16.7mm because of the receiver), 60mm at z=2200mm (allow ~2% deviation due to receiver), 92mm at z=3140mm (must match), 204mm at z=3880mm (must match).

### Prompt 24 — Mouthpiece compatibility check

> The horn should accept a standard alphorn mouthpiece with a 12mm-OD shank tip tapering to ~29mm at the cup shoulder over 79mm. Verify the mouthpiece seats by taper friction in the receiver. Calculate the depth at which shank OD equals receiver bore ID (linear taper from 16.7 to 12 over 42mm). Confirm it's a snug fit at a reasonable depth (~10-15mm into the receiver). The mouthpiece itself is supplied separately by the user — do not include it in the model. The Talbot 20mm 3D-printed mouthpiece STL from argobuilder.com works (note: that STL must be scaled to 10% in the slicer — Talbot exported it at 10× scale).

## Phase 10: Documentation

### Prompt 25 — README

> Create a comprehensive README.md for this GitHub repository. It should include:
>
> - Specifications table (pitch, dimensions, joint type)
> - File-by-file purpose
> - Hardware required (no O-rings — sealing is by friction + optional PTFE tape)
> - Build instructions starting with the joint test
> - Plate-by-plate batching plan
> - Recommended print settings (small-end-down orientation)
> - Assembly procedure
> - Mouthpiece sourcing notes (commercial or Talbot STL with 10% scaling)
> - Acoustic design summary with the harmonic series table and bore profile equations
> - Customization guide for the parametric constants
> - Credits to Jason Talbot's reference work
> - License placeholder

### Prompt 26 — Final snapshot

> Take a final snapshot.

## Anti-patterns and lessons learned

Things the original session tried that turned out to be wrong. Don't repeat these.

**O-ring grooves are not worth the trouble.** Sourcing 18 different stretch sizes (24mm to 168mm ID) is fiddly. The groove geometry creates printability issues (unsupported overhang above the groove). PLA-on-PLA friction at the bayonet is adequate; PTFE plumbers' tape solves any leak. The acoustic compliance of a brass-style instrument tolerates some leak at joints anyway.

**The OpenSCAD preview cannot be trusted for mesh integrity.** Geometry that looks like a single connected piece in the preview can export as multiple disconnected shells in the STL. Always import the STL into Orca Slicer and check for separate objects.

**Nested CSG operations create degenerate boundaries.** Subtraction shapes built as `difference()` of two cylinders (e.g., to make an annular ring) often have outer boundaries that lie nearly on the body's outer surface — within 0.1mm. CGAL handles these unreliably and produces disconnected mesh shells. Build subtraction shapes as single `rotate_extrude` polygons instead, with outer boundaries well past the body OD (5mm past).

**Adjacent cylinders sharing only a 2D face produce separate STL shells.** Stacking cylinders end-to-end (`translate([0,0,h]) cylinder(...)` immediately above another cylinder) creates a 2D shared face that triangulation can't reliably handle. The solution is to build the entire body+flare+collar profile as a single `rotate_extrude` polygon — one closed path, one revolution, one solid.

**Section labels are hard to place. The body wall between lugs is the only location that works.** The inner socket wall is not visible looking straight down into a 20mm-deep socket. The collar's top face would block joint sealing. The collar's outer cylindrical surface fails for angled curve sections. The body wall at z=18 between lugs is a simple cylindrical surface, identical for every section, always visible from outside the horn.

**Don't compromise the bore for printability.** Adding an inner ramp to make collar-down printing easier creates an annular pocket at every joint — 18 pockets in series destroys the air column. Either print small-end-down (no overhang issue) or use slicer-generated supports. Keep the bore profile pure.

**The receiver bore profile has a kink at z=42mm.** The default 8-step bore subdivision linearly interpolates across this kink and produces ~0.7mm error in the rendered bore at the kink. Section 1 needs special handling: separate the receiver subtraction from the trunk subdivision, with z=42 as the boundary.

**Lug bottoms have a 3.5mm overhang.** Unless the lugs are chamfered with a `hull()` of two cubes (small bottom slab + full top), the printer drools layers across this overhang and the lugs print rough. The chamfer reduces the overhang to 1mm without compromising the lock engagement at the lug top.

**The curve sections' body-to-collar transition is fixed in the polygon, not by adding a flange.** It's tempting to "patch" the body-to-collar ledge on the low side of curve sections by adding a separate flange or extending the collar downward. Every additive approach fails the same way: any tilted piece has its bottom edge at varying world z, dipping low on the LOW side where the body is narrow, so the bottom edge protrudes 2-6mm outboard of the body wall there and just relocates the severe overhang. The right fix is to move the body polygon's flare-top vertex to z = `len − collar_or × tan(angle)` so the body itself reaches `collar_or` at the lowest point of the tilted joint plane. The body's outer corner then coincides with the collar's bottom rim within 0.03mm and the overhang vanishes.

**Mirror text or it reads backwards.** Recessing text into a curved surface from outside, the natural orientation makes the text read mirrored when viewed from outside. Add a `mirror([1, 0, 0])` before linear_extrude to flip it. This was discovered after the first complete print attempt — the digits were perfectly legible but reversed.

## Tips for success

**Iterate in small steps.** Every time a change is made to body, flare, collar, or bayonet geometry, render a single section and verify visually before moving on. The original session repeatedly hit problems where a "small change" broke something three steps back.

**Take snapshots aggressively.** After every prompt that produces working geometry, ask Claude to take a snapshot. The snapshots are your rollback points when an experiment goes wrong.

**Trust the diagnostic file.** If you see disconnected meshes in Orca, don't try to reason your way to the cause — use the feature-toggle diagnostic file to bisect. The original session lost considerable time guessing at causes when a 5-minute bisection would have isolated the issue.

**Verify acoustic dimensions early.** Confirm the bore profile matches Talbot's reference points before adding joint geometry. Once joints are in place, it's harder to verify the bore is correct without unwinding work.

**Print test before committing.** Always print the joint test piece first. The bayonet clearance (`BAYONET_CL`) is tuned for typical PLA shrinkage but your printer/filament combination may differ.

**Check labels in the slicer view.** OpenSCAD's preview won't tell you if labels are extruding outward into empty space (no recess) or oriented backwards. Slice and look at the layers in Orca before printing.

## Approximate session length

The original session took several hours of iterative back-and-forth, with most time spent on the mesh-integrity debugging phase (Phase 5) and the labels (Phase 6). With this guide and the lessons baked in, expect 2-3 hours to recreate the design from scratch — assuming Claude correctly identifies the issues on the first prompt for each phase. Allow more time if you make modifications to dimensions or add features beyond what's described here.

## What this design assumes

- A printer with at least 256mm Z-height
- PLA or PETG filament (the bayonet clearances `BAYONET_CL = 0.25mm` are tuned for typical PLA shrinkage)
- A separately-sourced mouthpiece (commercial alphorn mouthpiece with ~12mm shank tip OD, or 3D-printed Talbot design scaled to 10% in slicer)
- PTFE plumbers' tape (optional, only if a joint leaks)
- No O-rings — sealing is by friction-fit at the bayonet plus optional PTFE tape

If your printer or filament differs, expect to print the joint test file first and adjust `BAYONET_CL` based on the fit you get.

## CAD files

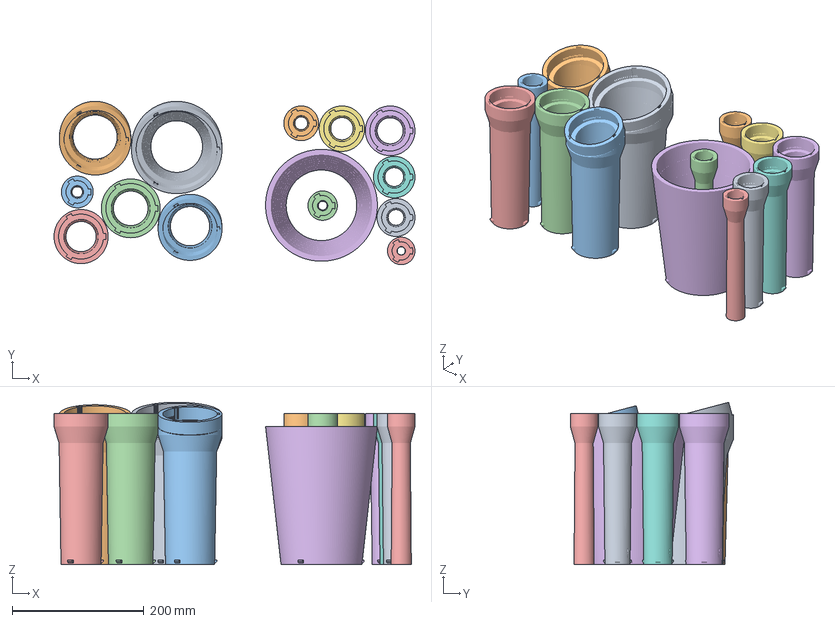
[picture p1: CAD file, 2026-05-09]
Bb_alphorn_print_layout.3mf
548.2 x 248.0 x 246.7 mm
Bb_alphorn_print_layout.stl_14
Bb_alphorn_print_layout.stl_13
Bb_alphorn_print_layout.stl_11
Bb_alphorn_print_layout.stl_10
Bb_alphorn_print_layout.stl_9
Bb_alphorn_print_layout.stl_8
Bb_alphorn_print_layout.stl_7
Bb_alphorn_print_layout.stl_6
Bb_alphorn_print_layout.stl_5
Bb_alphorn_print_layout.stl_4
Bb_alphorn_print_layout.stl_3
Bb_alphorn_print_layout.stl_2
Bb_alphorn_print_layout.stl_1
Bb_alphorn_print_layout.stl_12

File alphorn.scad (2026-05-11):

// ============================================================
//  PARAMETRIC 3D-PRINTABLE F ALPHORN
//  Based on Jason Talbot dimensions (argobuilder.com)
//  Designed for Bambu Lab X1C, PLA Wood Filament
//  All dimensions in mm unless noted
// ============================================================
//
//  The alphorn is a SINGLE CONTINUOUS TAPERED TUBE, 3880mm long.
//  There is no separate bell — the bell is simply the final
//  sections of the same bore, where the taper accelerates.
//
//  The bore is defined by two curve segments:
//    Trunk (z=0 to 3140mm):  power law
//    Bell  (z=3140 to 3880mm): quadratic, C1-continuous at join
//
//  The gentle curve of the instrument is achieved by angling
//  the mating faces of adjacent sections — no curved geometry
//  in any individual printed part.
//
//  TOTAL: 19 sections + mouthpiece + support foot
//  All sections fit within the X1C 256mm build volume.
// ============================================================

// ============================================================
//  RENDER CONTROL
//  Set RENDER_ASSEMBLY = true to preview the full horn.
//  For printing, set exactly one part flag to true at a time.
// ============================================================

RENDER_ASSEMBLY   = true;

RENDER_SECTION    = false;   // set SECTION_NUMBER below
SECTION_NUMBER    = 1;       // 1-19
// ============================================================
//  MASTER ACOUSTIC PARAMETERS
//  All from Talbot drawings (argobuilder.com)
// ============================================================

TOTAL_LENGTH      = 3880;    // mm  (trunk 3140 + bell 740)
TRUNK_LENGTH      = 3140;    // mm  where trunk bore law ends
BELL_LENGTH       = 740;     // mm  bell region (z=3140 to 3880)

// Bore confirmed reference points (Talbot drawings):
//   z=    0mm  ID= 14.00mm   (mouthpiece end)
//   z= 2200mm  ID= 60.00mm   (Talbot sheet 2, at 220cm)
//   z= 3140mm  ID= 92.00mm   (Talbot sheet 2, at 294cm)
//   z= 3880mm  ID=204.00mm   (Talbot sheet 3, bell mouth)

// Wall thickness — increased from 7/8 to 9/10 mm after structural failure
// testing showed the original walls were insufficient for the assembly
// bending loads at the collar-exit stress concentration.
WALL_TRUNK        = 9.0;     // mm  (was 7.0 — increased for structural strength)
WALL_BELL         = 10.0;    // mm  (was 8.0 — increased for structural strength)

// ============================================================
//  SECTION PARAMETERS
// ============================================================

NUM_SECTIONS      = 19;      // 19 x 204.2mm — required so the curve
                             //   sections (with angled female face) fit
                             //   within the X1C 256mm build height.
                             //   Section 18 was 258.7mm tall at 18-section
                             //   layout; reducing per-section length brings
                             //   the worst case down to ~248mm.
SECTION_LEN       = TOTAL_LENGTH / NUM_SECTIONS;  // 204.2mm

// ============================================================
//  CURVE PARAMETERS
// ============================================================
//  The traditional alphorn upward sweep is achieved by angling
//  the female end face of selected sections. Each angled joint
//  deflects the next section by the cut angle. Section bodies
//  remain straight frustums — the curve emerges from assembly.
//
//  Default: 45 degrees total bend, distributed across 3 joints
//  in the bell region (15->16, 16->17, 17->18).
//
//  No length is added. OD at faces is unchanged.
//  Wall thickness is preserved everywhere.

CURVE_TOTAL_DEG   = 45;      // total bend in the bell region
CURVE_JOINTS      = 3;       // distributed across this many joints
CURVE_PER_JOINT   = CURVE_TOTAL_DEG / CURVE_JOINTS;  // = 15 deg

// Which sections have angled female ends (last face = curve joint)
function is_curve_section(n) =
    (n >= NUM_SECTIONS - CURVE_JOINTS) && (n < NUM_SECTIONS);

// Cumulative rotation applied to a section in the assembly preview
// (sum of all curve angles before this section)
function cumulative_curve(n) =
    (n <= NUM_SECTIONS - CURVE_JOINTS) ? 0 :
    (n - (NUM_SECTIONS - CURVE_JOINTS)) * CURVE_PER_JOINT;

// ============================================================
//  BAYONET JOINT PARAMETERS
// ============================================================

BAYONET_LUGS      = 3;       // 3 lugs at 120 degrees
BAYONET_DEPTH     = 15;      // mm  axial travel from open face to lock position
BAYONET_LUG_H     = 3.5;    // mm  radial lug protrusion
BAYONET_LUG_W     = 8;      // mm  tangential lug width (along circumference)
BAYONET_LUG_T     = 5;      // mm  axial thickness of lug
BAYONET_COLLAR    = 20;      // mm  collar length each end
BAYONET_CL        = 0.25;   // mm  print clearance on lugs

// ============================================================
//  COLLAR-EXIT STRUCTURAL REINFORCEMENT
//  After printing, PLA Wood sections snapped at z = BAYONET_COLLAR
//  from the male end — the exact point where the male section exits
//  the female collar. This is a classic stress concentration: the
//  collar provides full lateral support for z < BAYONET_COLLAR, then
//  abruptly nothing, peaking bending stress at the rim.
//
//  Fix: a tapered buttress ring on every male end.
//  Starts at z = BAYONET_COLLAR with an extra COLLAR_REINF_T of radius,
//  then tapers smoothly back to the natural pipe OD over COLLAR_REINF_H.
//  This nearly doubles the section modulus at the stress concentration.
//
//  Verified to fit within the female collar_or for all 19 sections
//  (minimum clearance 1.2 mm at section 19, 3.1 mm at section 2).
// ============================================================
COLLAR_REINF_T    = 5.0;    // mm  extra radius at z=BAYONET_COLLAR
COLLAR_REINF_H    = 30.0;   // mm  taper length back to natural OD
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

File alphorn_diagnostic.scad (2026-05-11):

// ============================================================
//  ALPHORN DIAGNOSTIC: isolate which feature creates rings
//
//  USAGE:
//  Set each FEATURE_* flag to true/false and re-export STL.
//  Open the STL in Orca Slicer and use "split into objects" or
//  "auto-arrange". Count the disconnected pieces.
//
//  Start with everything OFF, then turn features ON one at a time
//  to identify which feature introduces the rings.
// ============================================================

FEATURE_FLARE          = true;   // The body→collar flare zone
FEATURE_FEMALE_COLLAR  = true;   // Outer collar wall above z=len
FEATURE_INNER_SOCKET   = true;   // The hollow inside the collar
FEATURE_L_CHANNELS     = true;   // Bayonet slot cuts in collar
FEATURE_SECTION_LABEL  = true;   // Recessed number text
FEATURE_COLLAR_CHAMFER = true;   // 45° bevel at collar top edge
FEATURE_MALE_LUGS      = true;   // 3 lugs at small end
FEATURE_ORING_GROOVE   = true;   // Annular groove at z=10
FEATURE_BORE           = true;   // Inner bore subtraction

// ---- SECTION GEOMETRY (use a mid-size straight section: section 8) ----
LEN          = 204.21;
OD0          = 52.98;     // small end OD
OD1          = 59.43;     // large end OD
ID0          = 38.78;
ID1          = 44.20;

// ---- BAYONET CONSTANTS ----
BAYONET_LUGS    = 3;
BAYONET_DEPTH   = 15;
BAYONET_LUG_H   = 3.5;
BAYONET_LUG_W   = 8;
BAYONET_LUG_T   = 5;
BAYONET_COLLAR  = 20;
BAYONET_CL      = 0.25;
ORING_DEPTH     = 2.5;
ORING_WIDTH     = 2.2;
ORING_Z         = 10;
WALL_TRUNK      = 7.0;
LUG_EMBED       = 1.0;
TEXT_SIZE       = 16;
TEXT_DEPTH      = 1.2;
TEXT_ANGLE      = 60;
COLLAR_CHAMFER  = 5.0;

// ---- DERIVED ----
flare_h    = FEATURE_FLARE ? 25 : 0;
body_h     = LEN - flare_h;
od_at_flare = OD0 + (OD1 - OD0) * (body_h / LEN);
socket_or  = OD1/2 + BAYONET_LUG_H + BAYONET_CL;
collar_or  = socket_or + WALL_TRUNK/2;
collar_h   = BAYONET_COLLAR;

difference() {
    // ---- OUTER HULL ----
    union() {
        // Body + flare + collar as one rotate_extrude polygon
        rotate_extrude(angle=360, $fn=128)
        polygon(points=[
            [OD0/2,        0],
            [od_at_flare/2, body_h],
            [collar_or,    LEN],
            [collar_or,    FEATURE_FEMALE_COLLAR ? LEN + collar_h : LEN],
            [0,            FEATURE_FEMALE_COLLAR ? LEN + collar_h : LEN],
            [0,            0]
        ]);

        // Male lugs
        if (FEATURE_MALE_LUGS) {
            lug_z_center = BAYONET_COLLAR - BAYONET_DEPTH;
            for (i = [0 : BAYONET_LUGS-1]) {
                rotate([0, 0, i * (360/BAYONET_LUGS)])
                translate([OD0/2 - LUG_EMBED, -BAYONET_LUG_W/2,
                           lug_z_center - BAYONET_LUG_T/2])
                cube([BAYONET_LUG_H + LUG_EMBED, BAYONET_LUG_W, BAYONET_LUG_T]);
            }
        }
    }

    // ---- BORE ----
    if (FEATURE_BORE) {
        translate([0, 0, -0.5])
        cylinder(h=LEN+1, r1=ID0/2, r2=ID1/2, $fn=128);
    }

    // ---- INNER SOCKET ----
    if (FEATURE_FEMALE_COLLAR && FEATURE_INNER_SOCKET) {
        translate([0, 0, LEN - 0.5])
        cylinder(h=collar_h + 1, r=OD1/2 + BAYONET_CL, $fn=128);
    }

    // ---- L-CHANNELS ----
    if (FEATURE_FEMALE_COLLAR && FEATURE_L_CHANNELS) {
        translate([0, 0, LEN]) {
            slot_half_angle = atan2(BAYONET_LUG_W/2 + BAYONET_CL, OD1/2 + BAYONET_CL);
            for (i = [0 : BAYONET_LUGS-1]) {
                rotate([0, 0, i * (360/BAYONET_LUGS)]) {
                    rotate([0, 0, -slot_half_angle])
                    translate([0, 0, BAYONET_COLLAR - BAYONET_DEPTH - BAYONET_LUG_T/2 - BAYONET_CL])
                    rotate_extrude(angle=2*slot_half_angle, $fn=128)
                    translate([OD1/2 + BAYONET_CL, 0])
                    square([BAYONET_LUG_H + 2*BAYONET_CL, BAYONET_COLLAR + 1]);

                    rotate([0, 0, slot_half_angle])
                    translate([0, 0, BAYONET_COLLAR - BAYONET_DEPTH - BAYONET_LUG_T/2 - BAYONET_CL])
                    rotate_extrude(angle=30, $fn=128)
                    translate([OD1/2 + BAYONET_CL, 0])
                    square([BAYONET_LUG_H + 2*BAYONET_CL, BAYONET_LUG_T + 2*BAYONET_CL]);
                }
            }
        }
    }

    // ---- SECTION LABEL ----
    if (FEATURE_FEMALE_COLLAR && FEATURE_SECTION_LABEL) {
        translate([0, 0, LEN])
        rotate([0, 0, TEXT_ANGLE])
        translate([OD1/2 + BAYONET_CL, 0, BAYONET_COLLAR / 2])
        rotate([0, 90, 0])
        mirror([1, 0, 0])
        linear_extrude(height=TEXT_DEPTH)
        text("8", size=TEXT_SIZE, halign="center", valign="center",
             font="Liberation Sans:style=Bold", $fn=32);
    }

    // ---- COLLAR CHAMFER ----
    if (FEATURE_FEMALE_COLLAR && FEATURE_COLLAR_CHAMFER) {
        translate([0, 0, LEN + collar_h - COLLAR_CHAMFER])
        cylinder(h=COLLAR_CHAMFER + 1,
                 r1=collar_or - COLLAR_CHAMFER,
                 r2=collar_or + 1,
                 $fn=128);
    }

    // ---- ORING GROOVE ----
    if (FEATURE_ORING_GROOVE) {
        translate([0, 0, ORING_Z])
        rotate_extrude(angle=360, $fn=128)
        translate([OD0/2 - ORING_DEPTH, 0])
        square([ORING_DEPTH + 5, ORING_WIDTH]);
    }
}

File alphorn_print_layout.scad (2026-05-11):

// ============================================================
//  ALPHORN PRINT LAYOUT  (self-contained)
//  Based on Jason Talbot dimensions (argobuilder.com)
//  Designed for Bambu Lab X1C, PLA Wood Filament
//  All dimensions in mm unless noted
// ============================================================
//
//  All 19 sections and the support foot are
//  arranged on the XY plane in their optimal print orientation.
//  This file is SELF-CONTAINED — no reference to alphorn.scad.
//
//  PRINT ORIENTATION:
//    Sections — vertical, small end (mouthpiece side) DOWN
//    Foot     — vertical, base DOWN
//
//  Section heights (max, including angled collar lift on curve sections):
//    Sections  1-15:  224mm  (body 204mm + 20mm collar)
//    Section  16:    240mm  (body + tilted collar)
//    Section  17:    243mm  (body + tilted collar, larger OD)
//    Section  18:    248mm  (body + tilted collar, larger OD)
//    Section  19:    204mm  (body only — bell mouth, no collar)
//  All under 256mm X1C build height ✓
//
//  BATCHING PLAN (which sections fit together on a 256mm bed):
//    Plate  1: sections  1 +  2  (~110mm wide)
//    Plate  2: sections  3 +  4  (~120mm wide)
//    Plate  3: sections  5 +  6  (~135mm wide)
//    Plate  4: sections  7 +  8  (~155mm wide)
//    Plate  5: sections  9 + 10  (~180mm wide)
//    Plate  6: sections 11 + 12  (~205mm wide)
//    Plate  7: sections 13 + 14  (~235mm wide)
//    Plate  8: section  15 only
//    Plate  9: section  16 only
//    Plate 10: section  17 only
//    Plate 11: section  18 only
//    Plate 12: section  19 only
//
//  SUPPORT NOTE:
//    Sections 1-15  — no supports needed
//    Sections 16-18 — angled female face at top; check slicer
//                     for overhang, may need partial supports
//    Section 19     — large bell mouth, no supports
//    Mouthpiece     — no supports (cup face down)
// ============================================================

// ============================================================
//  MASTER ACOUSTIC PARAMETERS
//  All from Talbot drawings (argobuilder.com)
// ============================================================

TOTAL_LENGTH      = 3880;    // mm  (trunk 3140 + bell 740)
TRUNK_LENGTH      = 3140;    // mm  where trunk bore law ends
BELL_LENGTH       = 740;     // mm  bell region (z=3140 to 3880)

// Bore confirmed reference points (Talbot drawings):
//   z=    0mm  ID= 14.00mm   (mouthpiece end)
//   z= 2200mm  ID= 60.00mm   (Talbot sheet 2, at 220cm)
//   z= 3140mm  ID= 92.00mm   (Talbot sheet 2, at 294cm)
//   z= 3880mm  ID=204.00mm   (Talbot sheet 3, bell mouth)

// Wall thickness — increased from 7/8 to 9/10 mm after structural failure
// testing showed the original walls were insufficient for the assembly
// bending loads at the collar-exit stress concentration.
WALL_TRUNK        = 9.0;     // mm  (was 7.0 — increased for structural strength)
WALL_BELL         = 10.0;    // mm  (was 8.0 — increased for structural strength)

// ============================================================
//  SECTION PARAMETERS
// ============================================================

NUM_SECTIONS      = 19;      // 19 x 204.2mm — required so the curve
                             //   sections (with angled female face) fit
                             //   within the X1C 256mm build height.
                             //   Section 18 was 258.7mm tall at 18-section
                             //   layout; reducing per-section length brings
                             //   the worst case down to ~248mm.
SECTION_LEN       = TOTAL_LENGTH / NUM_SECTIONS;  // 204.2mm

// ============================================================
//  CURVE PARAMETERS
// ============================================================
//  The traditional alphorn upward sweep is achieved by angling
//  the female end face of selected sections. Each angled joint
//  deflects the next section by the cut angle. Section bodies
//  remain straight frustums — the curve emerges from assembly.
//
//  Default: 45 degrees total bend, distributed across 3 joints
//  in the bell region (15->16, 16->17, 17->18).
//
//  No length is added. OD at faces is unchanged.
//  Wall thickness is preserved everywhere.

CURVE_TOTAL_DEG   = 45;      // total bend in the bell region
CURVE_JOINTS      = 3;       // distributed across this many joints
CURVE_PER_JOINT   = CURVE_TOTAL_DEG / CURVE_JOINTS;  // = 15 deg

// Which sections have angled female ends (last face = curve joint)
function is_curve_section(n) =
    (n >= NUM_SECTIONS - CURVE_JOINTS) && (n < NUM_SECTIONS);

// Cumulative rotation applied to a section in the assembly preview
// (sum of all curve angles before this section)
function cumulative_curve(n) =
    (n <= NUM_SECTIONS - CURVE_JOINTS) ? 0 :
    (n - (NUM_SECTIONS - CURVE_JOINTS)) * CURVE_PER_JOINT;

// ============================================================
//  BAYONET JOINT PARAMETERS
// ============================================================

BAYONET_LUGS      = 3;       // 3 lugs at 120 degrees
BAYONET_DEPTH     = 15;      // mm  axial travel from open face to lock position
BAYONET_LUG_H     = 3.5;    // mm  radial lug protrusion
BAYONET_LUG_W     = 8;      // mm  tangential lug width (along circumference)
BAYONET_LUG_T     = 5;      // mm  axial thickness of lug
BAYONET_COLLAR    = 20;      // mm  collar length each end
BAYONET_CL        = 0.25;   // mm  print clearance on lugs

// Collar-exit structural reinforcement (see alphorn.scad for full rationale)
COLLAR_REINF_T    = 5.0;    // mm  extra radius at z=BAYONET_COLLAR
COLLAR_REINF_H    = 30.0;   // mm  taper length back to natural OD
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

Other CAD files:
alphorn_stand.scad
AlphornPrintModel.scad
Bb_alphorn.scad
Bb_alphorn_print_layout.scad
HornMouthpieceAdapter.scad
alphorn_joint_test.scad

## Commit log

2026-05-05 This is an initial commit
    [AlphornPrintModel.scad]
2026-05-06 Add HornMouthpieceAdapter with rounded bottom cylinder edges
    - Add HornMouthpieceAdapter.scad: adapter geometry for horn mouthpiece
    - Bottom cylindrical base (9mm tall, 12.5mm radius) has 1mm fillet on top and bottom edges via rotate_extrude offset technique
    - High-resolution cylinders using $fn=360 for smooth output
    - Also add alphorn.scad to version control
    [HornMouthpieceAdapter.scad, alphorn.scad]
2026-05-06 Refactor alphorn model: remove print ramp, add Bb conversion guide, add print layout
    - Remove PRINT_RAMP internal frustum from horn_section (overhang fix
    moved to separate print layout approach)
    - Fix mirrored section labels with mirror([1,0,0]) transform
    - Add Convert Model to Bb.md documenting parameter changes for Bb tuning
    - Add alphorn_print_layout.scad for flat print arrangement
    - Update README and Recreate with Claude docs
    - Remove AlphornPrintModel.scad (superseded by alphorn_print_layout.scad)
    - Minor fix to HornMouthpieceAdapter.scad
    [HornMouthpieceAdapter.scad, alphorn.scad, alphorn_print_layout.scad]
2026-05-08 Refactor curve section geometry with precise flare-to-collar transition
    - Calculate flare_top_z_c where flare reaches collar radius
    - Eliminates body-to-collar ledge on low side of tilted joint
    - Improves manifold integrity with explicit geometry
    - Add comprehensive comments explaining the geometry rationale
    [alphorn.scad, alphorn_print_layout.scad]
2026-05-08 Document O-ring sealing system and assembly procedures
    - Add O-ring seals to materials list and specs
    - Include detailed O-ring sizing table (18 O-rings, 2mm cross-section)
    - Add O-ring groove verification step
    - Update assembly instructions to include O-ring seating
    - Clarify airtightness depends on O-ring fit
    - Add license placeholder for user selection
2026-05-08 Refactor documentation and standardize guide filenames
    - Update README to describe friction/PTFE joint sealing and revised print notes
    - Extend Bb conversion guide with curve flare geometry validation guidance
    - Replace spaced-title recreate guide with underscored filename
2026-05-09 Add Bb alphorn files and update conversion docs
    [Bb_alphorn.scad, Bb_alphorn_print_layout.scad]
2026-05-09 Add Orca Slicer file
    [Bb_alphorn_print_layout.3mf]
2026-05-11 Add stand, diagnostic, joint test, print layout updates, and project snapshot
    [alphorn.scad, alphorn_diagnostic.scad, alphorn_joint_test.scad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]
